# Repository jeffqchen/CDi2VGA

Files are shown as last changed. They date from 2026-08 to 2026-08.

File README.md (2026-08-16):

# HD15 Port Add-on for Phlips CD-i

## Introduction

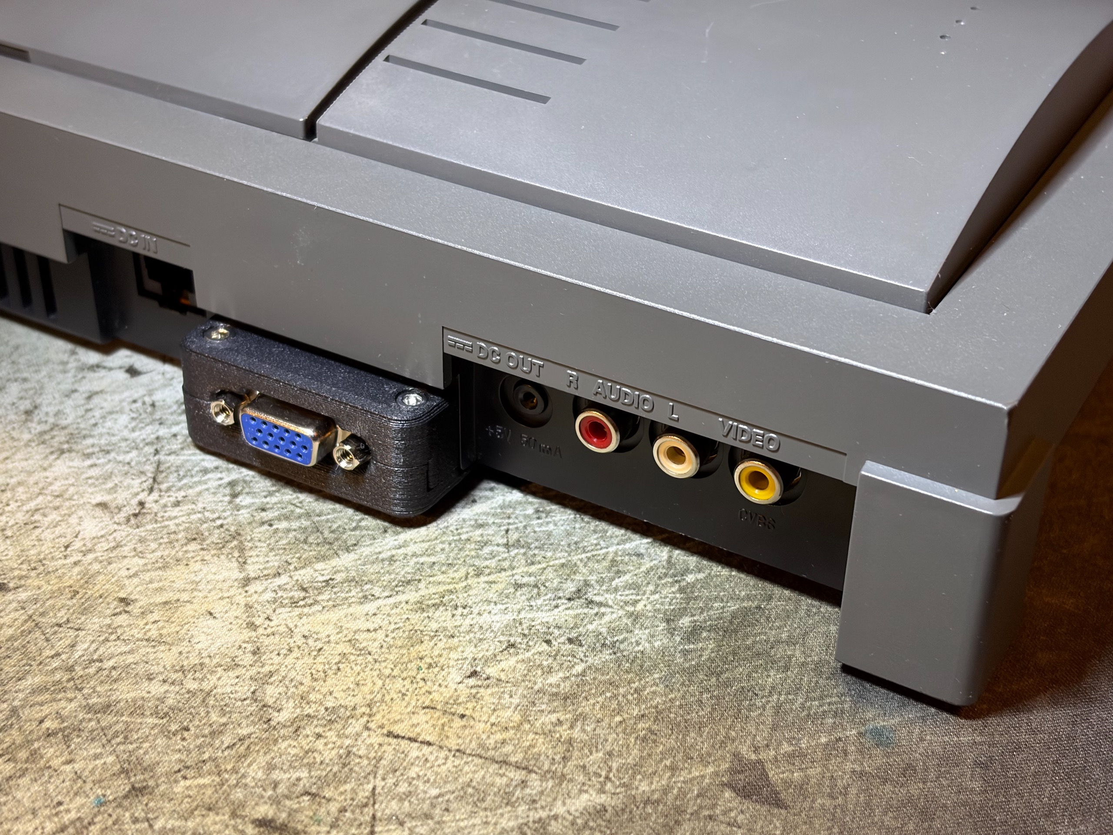
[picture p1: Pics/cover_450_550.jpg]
Philips CD-i 450 with HD15 Addon


The Philips CD-i can be modded with RGB output. However the actual output port sometimes involve cutting big holes or removing the Composite Video jack to fit. Therefore, I have come up this addon to fit an HD15 port onto the grills on the back of the console.

## Pin Definition

The pin definition follows the standard of my [VGA Dongle Series](https://github.com/jeffqchen/Console-VGA-Dongle-Series), which carries RGBS plus stereo audio.

- Pin 1-3: RGB signals
- Pin 13: HSync/CSync (connect to `CS-TTL` or `CS-75`)
- Pin 14: VSync (normally unpopulated)
- Pin 5, 6-8, 10: Ground
- Pin 12 & 15: Audio L & R
- Pin 9: Fused 5V

## Compatibility

This VGA signal is compatible with all major scalers.
- RetroTINK 5X - with my [dock](https://github.com/jeffqchen/RetroTINK-5X-SCART-Dock)
- RetroTINK 4K - directly connect to the `HD15` port or through my [SCART2VGA adapter](https://github.com/jeffqchen/RetroTINK-4K-SCART2VGA-Adapter)
- OSSC - directly connect to AV3 (VGA) port **IF** `CS_TTL` is connected to `Pin 13`
- GBSControl

## Currently supported Models
- CD-i 450 & 550 - [Guide](./450%20%26%20550/README.md)

-----------

Shield: [][cc-by-sa]

This work is licensed under a
[Creative Commons Attribution-ShareAlike 4.0 International License][cc-by-sa].

[][cc-by-sa]

[cc-by-sa]: http://creativecommons.org/licenses/by-sa/4.0/
[cc-by-sa-image]: https://licensebuttons.net/l/by-sa/4.0/88x31.png
[cc-by-sa-shield]: https://img.shields.io/badge/License-CC%20BY--SA%204.0-lightgrey.svg

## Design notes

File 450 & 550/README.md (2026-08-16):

# Building Guide for Philips CD-i 450 & 550

Cover

## Introduction

This variant fits the CD-i 450 & 550, since both share the same chassis and motherboard design. It utilizes a section of rear vents, and require two holes drilled on the bottom of the casing for installation. The final result is slick and does not require cutting additional holes or removing the Composite Video jack.

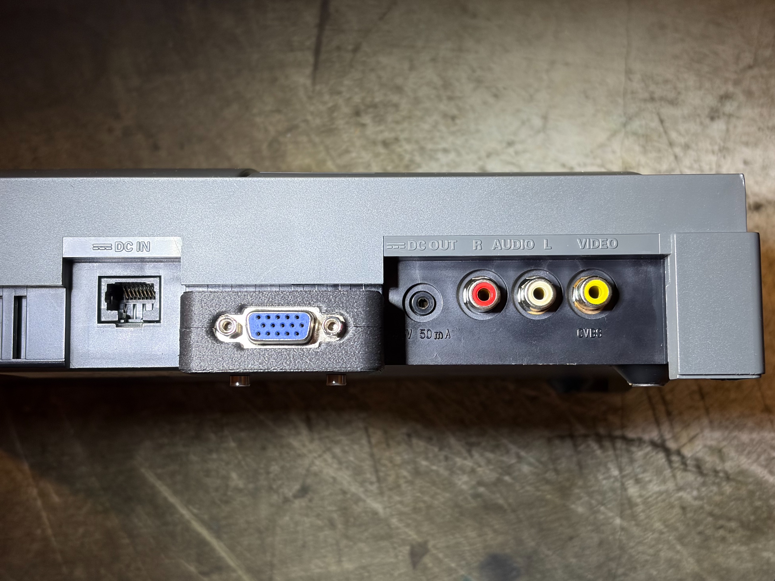
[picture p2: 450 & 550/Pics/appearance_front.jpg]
Front View

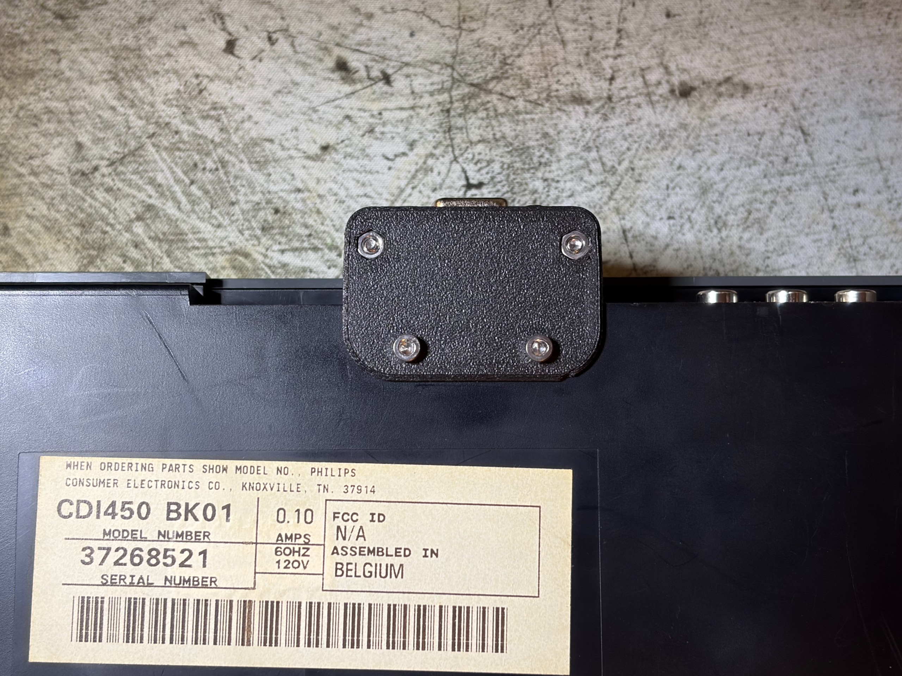
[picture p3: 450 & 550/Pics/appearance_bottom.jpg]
Bottom View

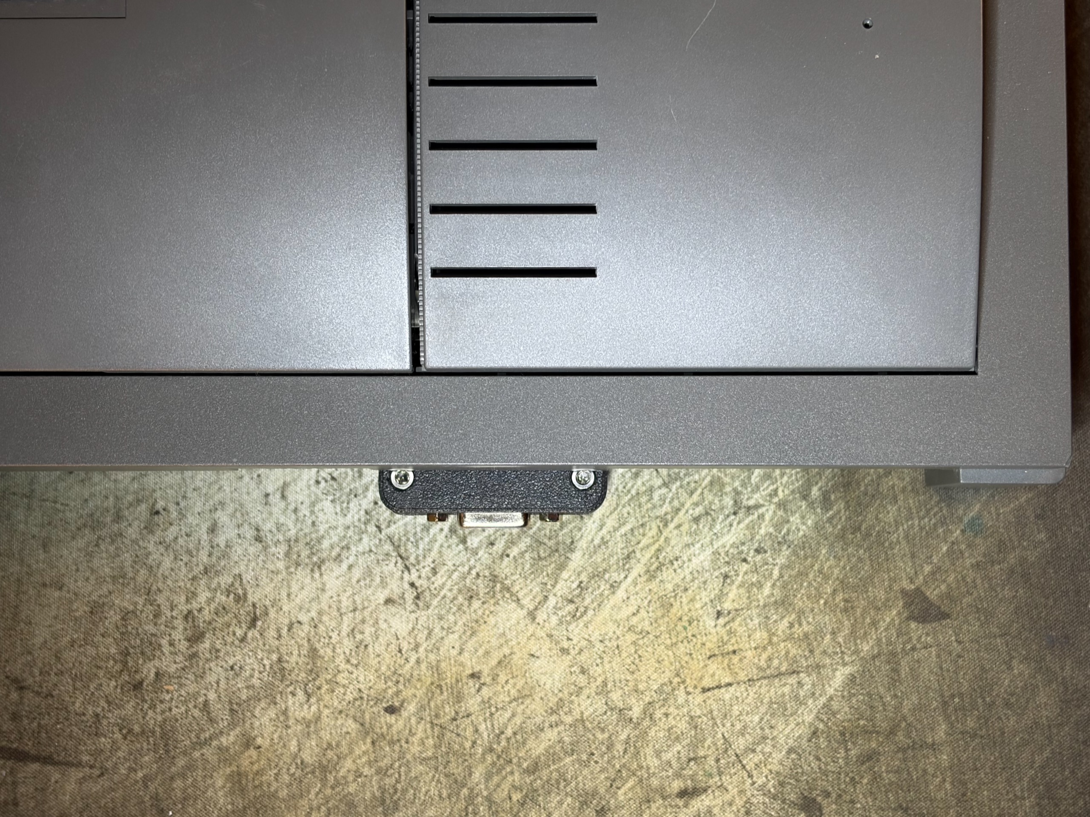
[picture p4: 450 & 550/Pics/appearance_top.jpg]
Top View


Since the original Composite Video jack is preserved, it is possible to output both CVBS and RGBS at the same time.

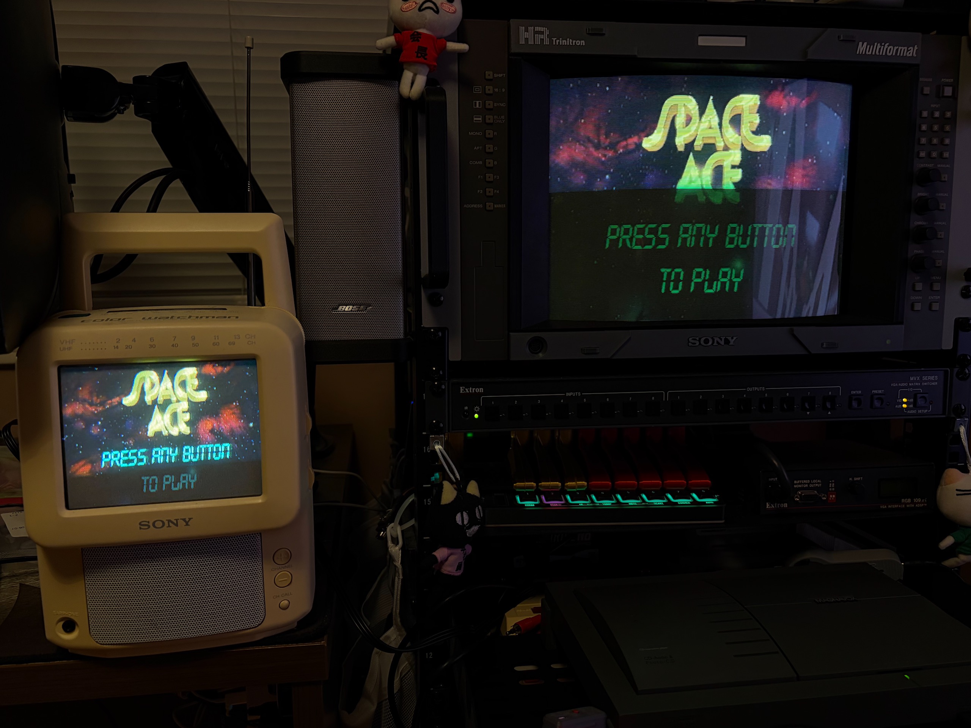
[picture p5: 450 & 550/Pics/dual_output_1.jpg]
Dual Output 1

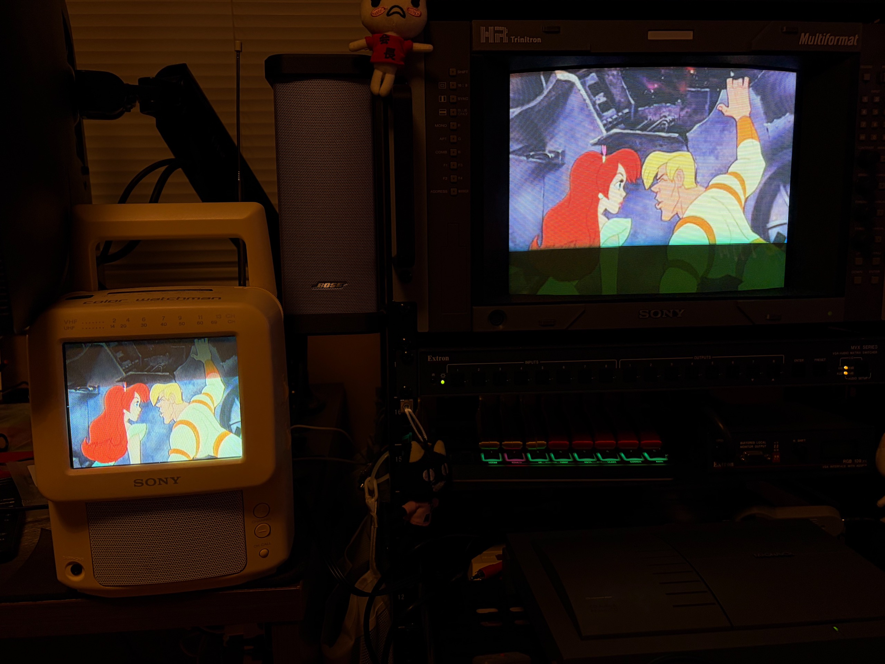
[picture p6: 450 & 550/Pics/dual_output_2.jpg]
Dual Output 2


## Parts

- 3D Printed parts - [STL Files](./3D%20Print)
- PCB - [Gerber File](./KiCAD/jlcpcb/gerber/CD-i%20450%20VGA%20Add-on.zip)
- VGA Port Slim, Female - [Link](https://github.com/jeffqchen/JeffParts/blob/main/Connectors/HD15/Slim/Female%20PCB/info.md)
- (Optional) Resistors, imperial 0603
  - R1: 0 Ohm, for fusing the 5V power line
  - R2: 1M Ohm, for connecting the VGA cable shielding to ground with ESD protection
- M2/M3 screw and hex nut - [Link](https://github.com/jeffqchen/JeffParts/blob/main/Parts/M2%20M3%20Hex%20Screw%20%26%20Nut/info.md)
  - 2x M3x8 screws
  - 2x M3x16 screws
  - 4x M3 nuts
- Colored wire at around 15cm

## Drilling The Chassis

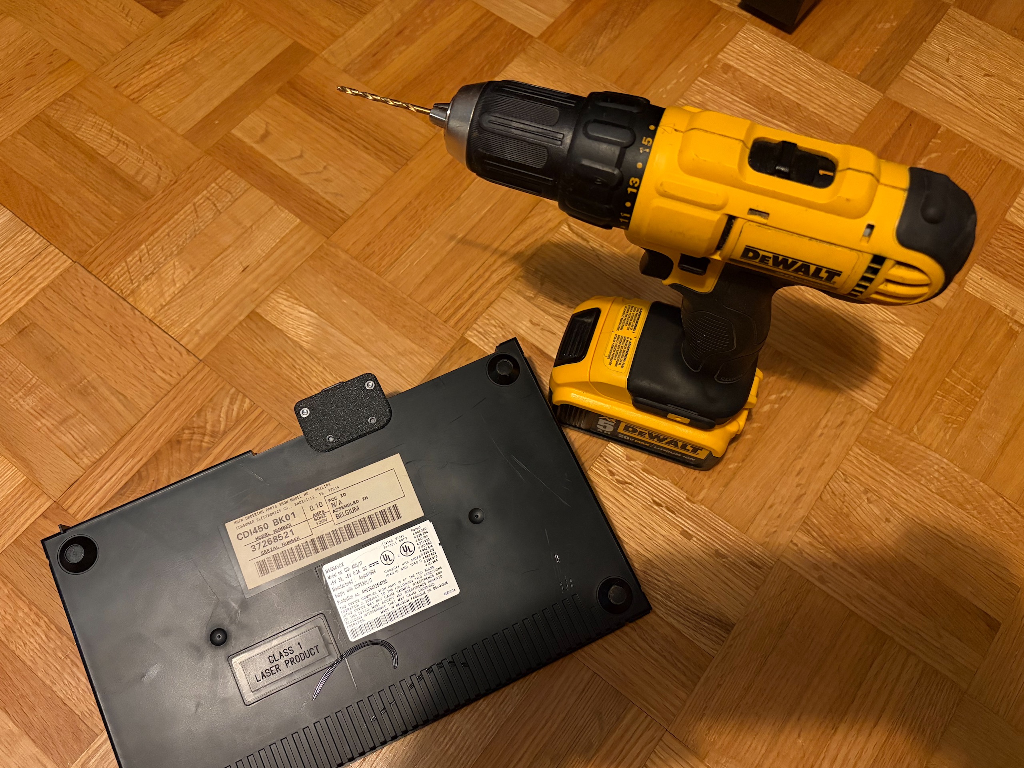
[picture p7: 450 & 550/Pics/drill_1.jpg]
Drilling 1


Assembly the 3D printed pieces together with screw and nuts, put it in place and use the two holes on the bottom as a guide to drill. The size of the bit should be 3mm / 1/8".

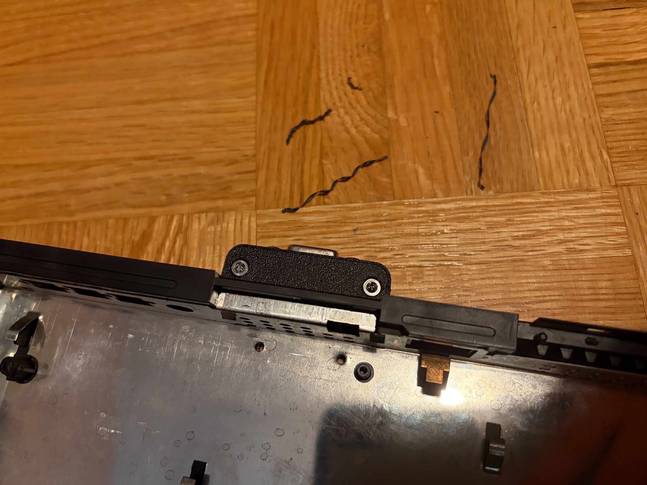
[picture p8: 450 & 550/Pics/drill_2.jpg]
Drilling 2


Fit a piece of wood on the inside of the metal shielding for taking the pressure of the drill. Make sure to drill through both the plastic and the metal shielding.

After the holes are drilled, remove the 3D printed shell and disassemble it for the next step.

## PCB & Shell Assembly

There is nothing special about the soldering.

Resistor R1 and R2 are optional if you have requirements for 5V power or ESD consideration.

Make sure the VGA port is soldered on properly with no gap between the base of the port and the PCB.

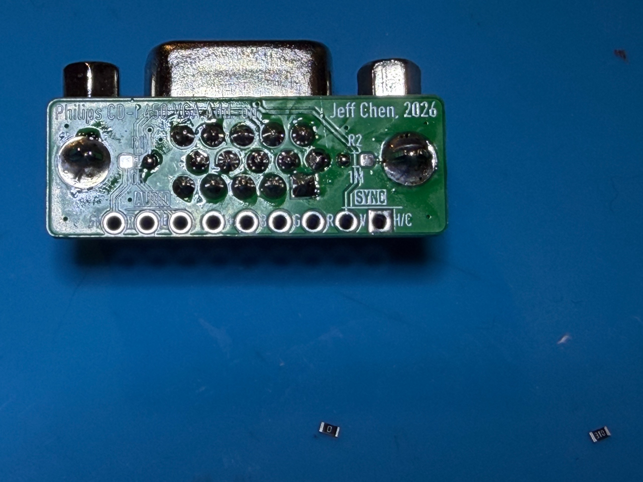
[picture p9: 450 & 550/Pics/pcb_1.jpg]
PCB Assembly 1


Signals are marked on the PCB. Use colored wires of your choice to help with later installation.

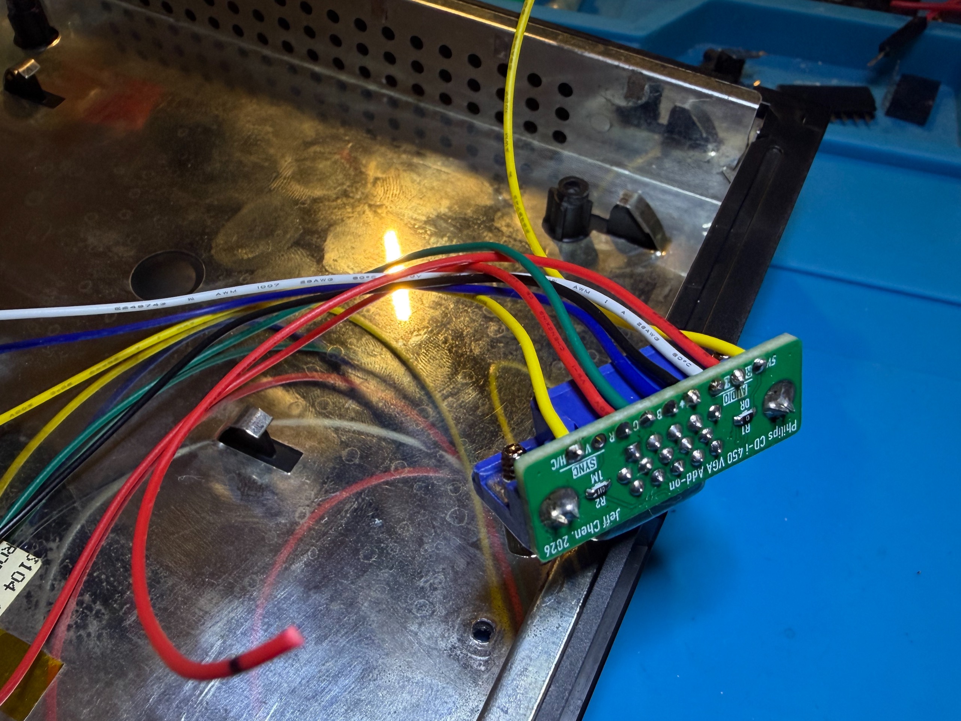
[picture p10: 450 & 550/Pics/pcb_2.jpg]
PCB Assembly 2


Finally, install the PCB assembly into the 3D printed shell with M3x16mm screws and nuts.

## Installation

Thread the wires from the various vents into the metal shielding.

Note the first and last vent are used by the shell and should not have wires going through them. 

On the inside, I mainly used the top row holes since the lower ones might interfere with the motherboard.

Make sure the wires are not played with or bent too much during this step, as they tend to break at the solder joint.

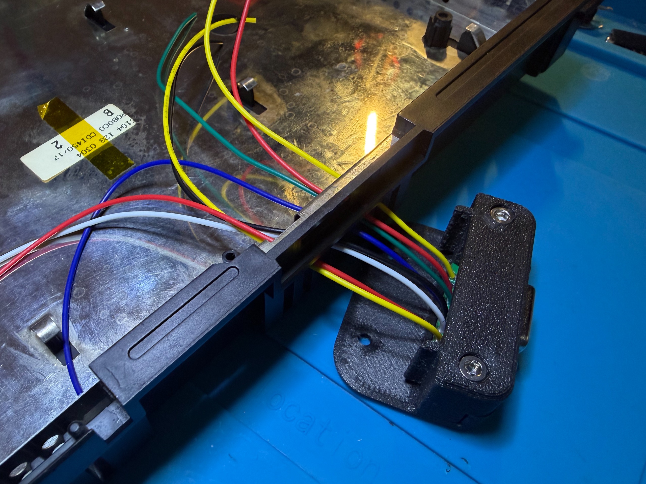
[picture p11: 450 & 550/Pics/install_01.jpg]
Installation 1

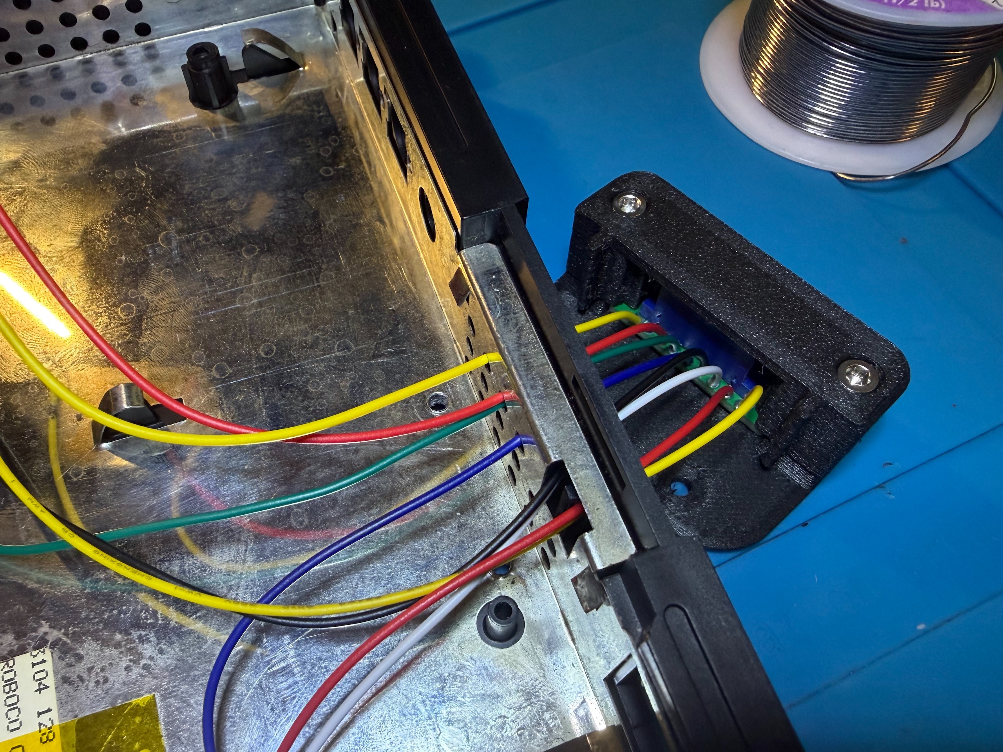
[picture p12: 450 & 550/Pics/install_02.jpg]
Installation 2


After threading all the wires, carefully close the port assembly onto the back of the plastic chassis.

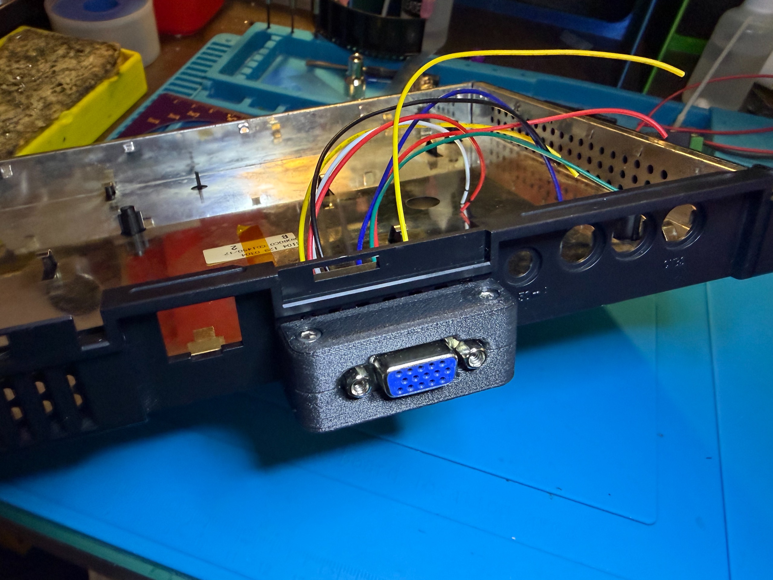
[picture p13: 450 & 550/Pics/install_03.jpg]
Installation 3

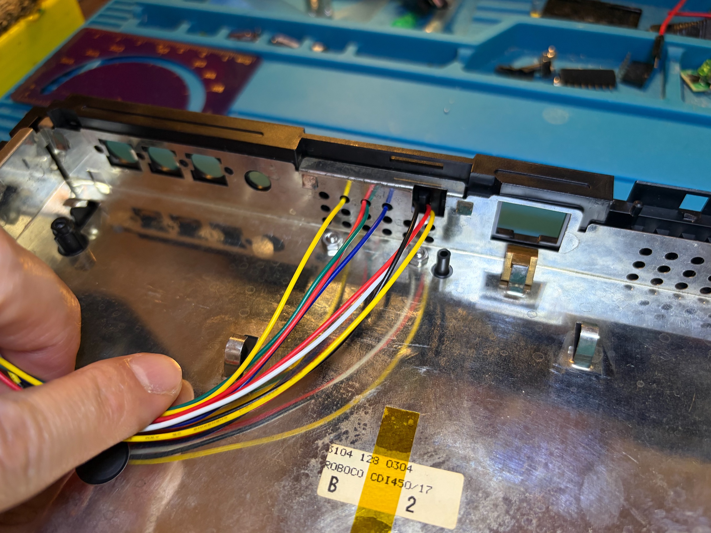
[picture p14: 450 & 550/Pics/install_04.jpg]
Installation 4


Insert two M3x8mm screws from the bottom of the console.

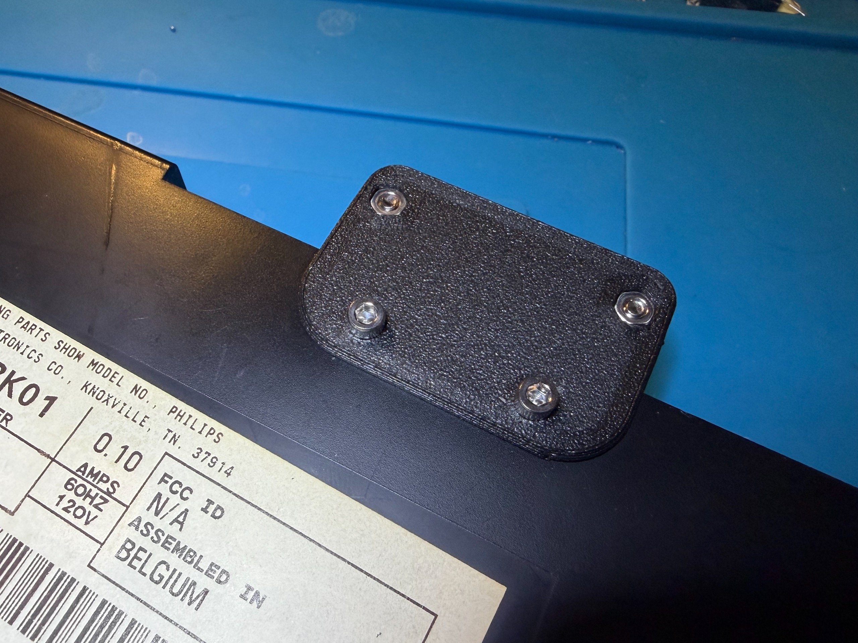
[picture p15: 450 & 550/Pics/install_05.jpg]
Installation 5


Use two M3 nuts to secure the screws and the assembly.

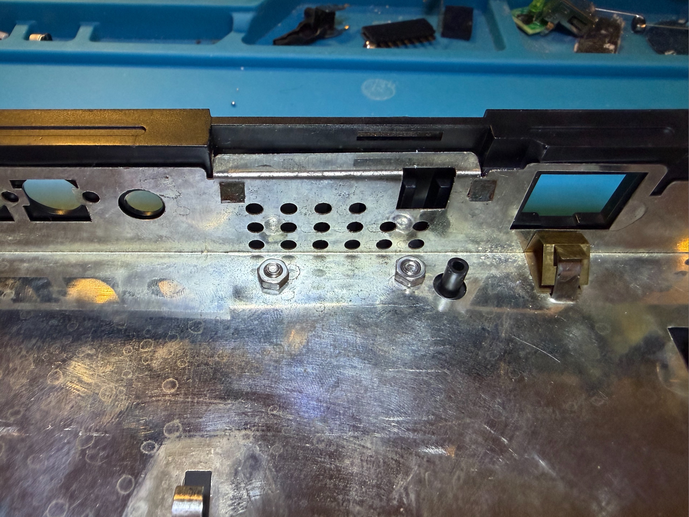
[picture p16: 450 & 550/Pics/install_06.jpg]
Installation 6


Before installing the motherboard back into the chassis, cut the 4 protruding capacitor leads from under the board to make sure they would not touch the newly installed nuts.

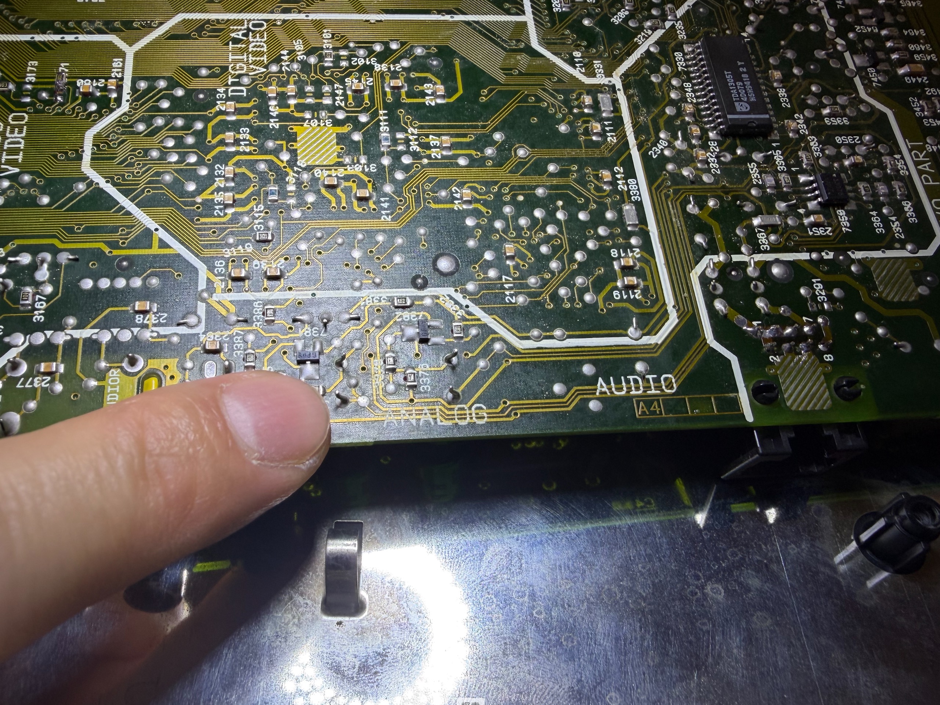
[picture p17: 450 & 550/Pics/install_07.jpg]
Installation 7


Install the motherboard and make sure all the wires are accounted for.

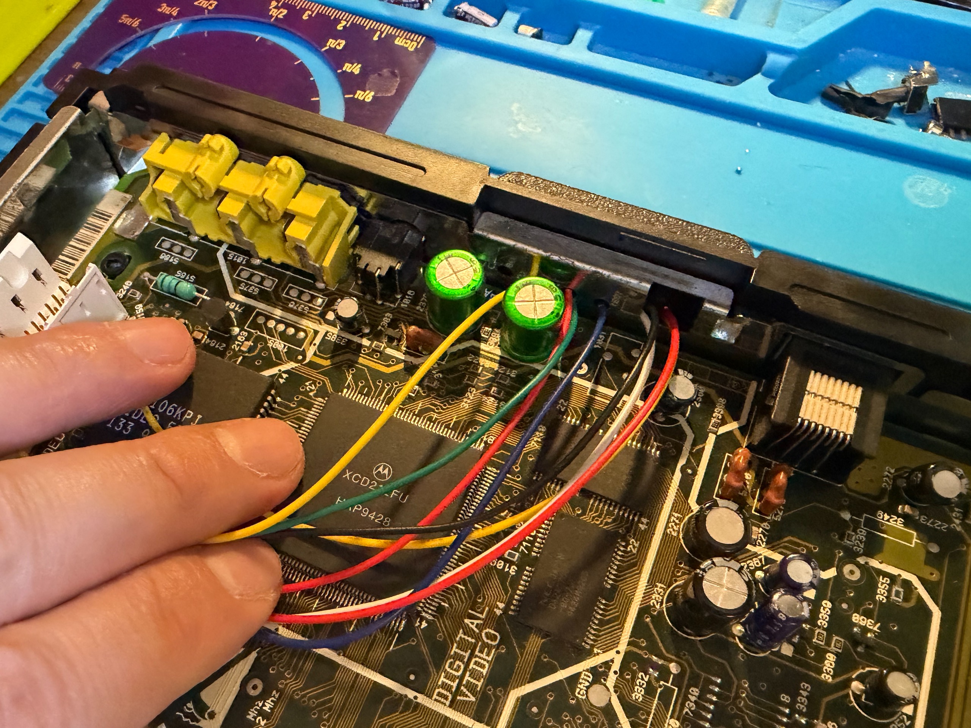
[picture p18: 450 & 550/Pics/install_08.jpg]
Installation 8


## Finalizing

Here is an example of my own RGB mod install. I trimmed the wires to better fit them on the inside of the console.

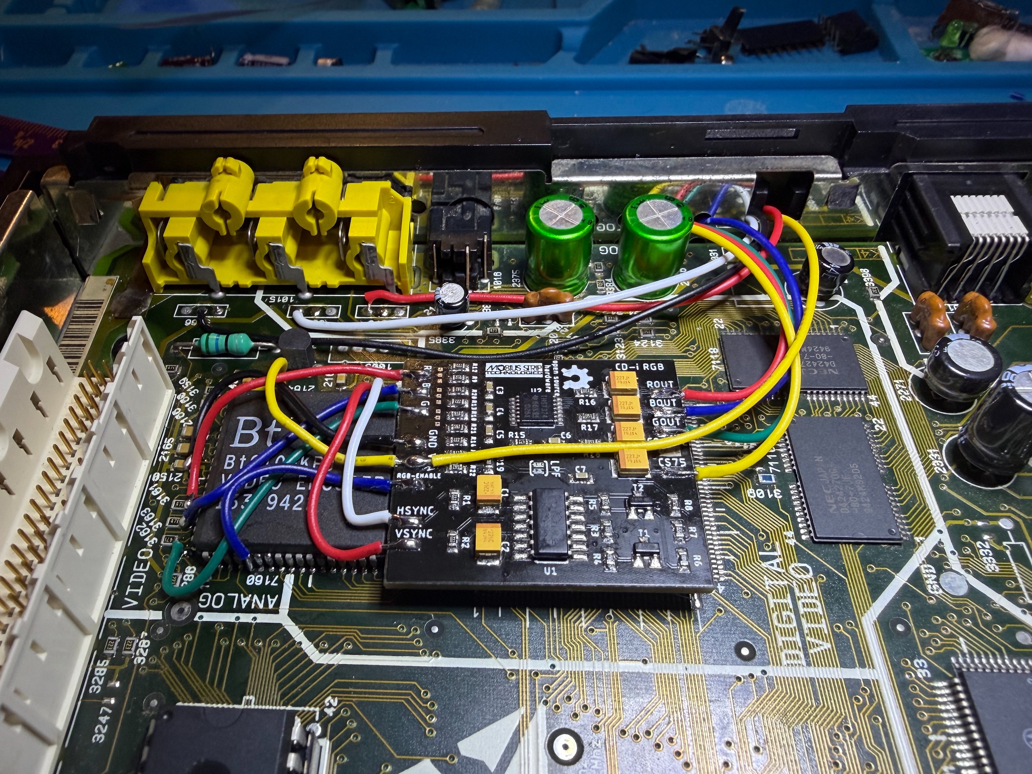
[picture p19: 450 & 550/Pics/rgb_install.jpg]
RGB Installation


When closing down the top metal shielding, make sure to check if any wire is being crushed by the edge of the top shielding (mine was fine.)

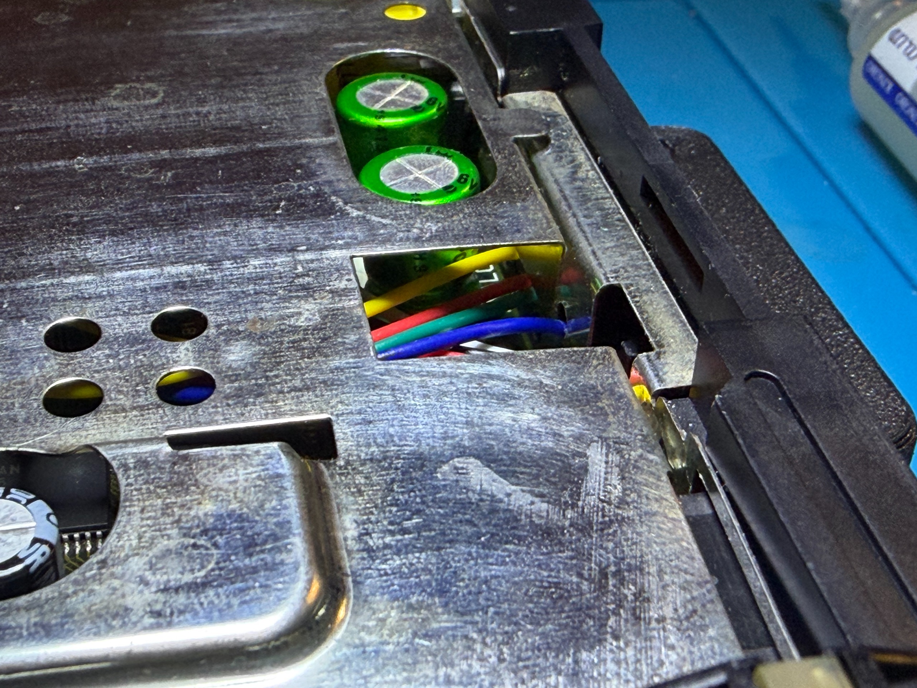
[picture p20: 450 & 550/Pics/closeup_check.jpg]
Closing check


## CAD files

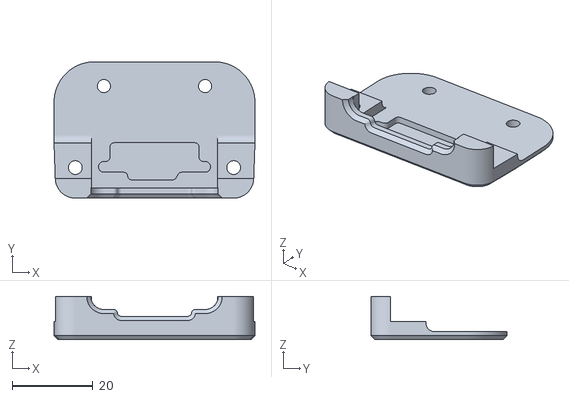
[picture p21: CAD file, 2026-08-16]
450 & 550/3D Print/Shell Bottom.stl
49.7 x 33.7 x 10.7

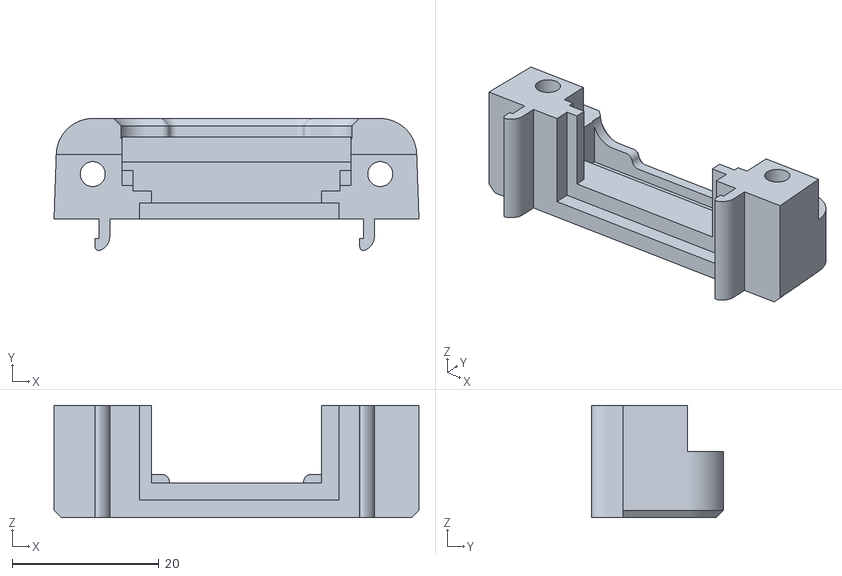
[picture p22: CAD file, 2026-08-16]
450 & 550/3D Print/Shell Top.stl
49.7 x 18.0 x 15.3

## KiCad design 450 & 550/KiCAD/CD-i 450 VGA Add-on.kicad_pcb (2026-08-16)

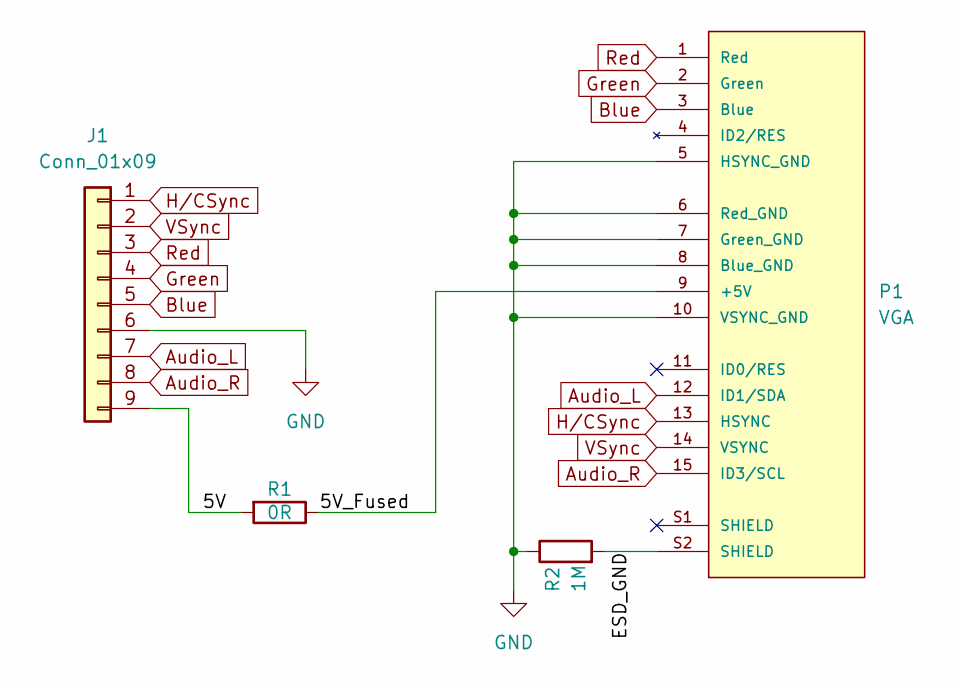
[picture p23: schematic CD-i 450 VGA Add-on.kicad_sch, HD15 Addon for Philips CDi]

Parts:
J1: Conn_01x09; PinHeader_1x09_P2.54mm_Vertical
P1: VGA; VGA_female_rightangle_slim; PARTREV N/A
R1: 0R; R_0603_1608Metric_Pad0.98x0.95mm_HandSolder
R2: 1M; R_0603_1608Metric_Pad0.98x0.95mm_HandSolder

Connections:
/5V: J1.9, R1.2
/5V_Fused: P1.9 (+5V), R1.1
/ESD_GND: P1.S2 (SHIELD), R2.2
Audio_L: J1.7, P1.12 (ID1/SDA)
Audio_R: J1.8, P1.15 (ID3/SCL)
Blue: J1.5, P1.3 (Blue)
GND: J1.6, P1.5 (HSYNC_GND), P1.6 (Red_GND), P1.7 (Green_GND), P1.8 (Blue_GND), P1.10 (VSYNC_GND), R2.1
Green: J1.4, P1.2 (Green)
H/CSync: J1.1, P1.13 (HSYNC)
Red: J1.3, P1.1 (Red)
VSync: J1.2, P1.14 (VSYNC)

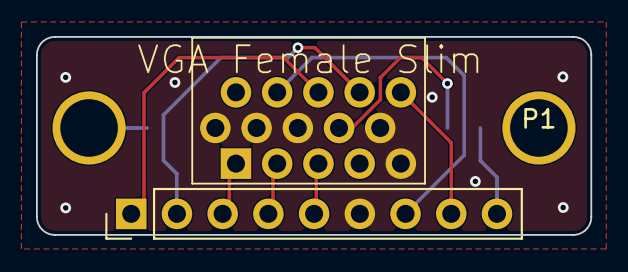
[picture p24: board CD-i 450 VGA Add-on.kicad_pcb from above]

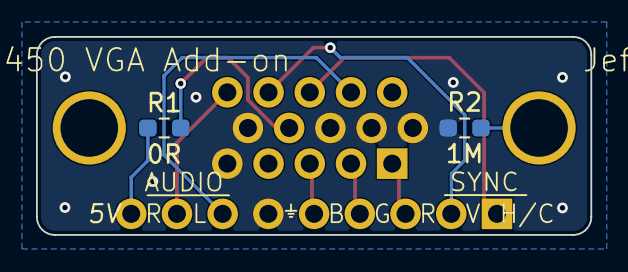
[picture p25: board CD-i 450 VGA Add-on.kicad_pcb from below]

Board: 2 copper layers, 30.8 x 11.0 mm, 4 parts (2 on the bottom side), 11 nets.

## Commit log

2026-08-16 Initial file upload for 450 & 550
    [CD-i 450 VGA Add-on-CuBottom.gbr, CD-i 450 VGA Add-on-CuTop.gbr, CD-i 450 VGA Add-on-EdgeCuts.gbr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]
2026-08-16 Update README with VGA pin definitions and compatibility
    Added pin definitions and compatibility information for VGA output.
2026-08-16 Add building guide for Philips CD-i 450 & 550
    Added detailed building guide for Philips CD-i 450 & 550, including parts list, PCB assembly instructions, and chassis drilling steps.
2026-08-16 Change PCB link to HTML anchor tag
    Updated the PCB link to use an HTML anchor tag for better accessibility.
2026-08-16 Enhance README with installation instructions and images
    Added images and detailed instructions for drilling, assembly, and installation of the VGA add-on for Philips CD-i 450 & 550.
2026-08-16 Update README with optional resistor information
    Added optional resistor details for 5V power and ESD protection in the assembly instructions.
2026-08-16 Update PCB assembly instructions in README.md
    Rearranged PCB assembly instructions and clarified optional components.
2026-08-16 Fix typo in README regarding resistor options
2026-08-16 Update installation instructions in README
    Clarified instructions for threading wires into metal shielding and noted vent usage.
2026-08-16 Refine wire installation instructions in README
    Reorganize instructions for clarity and emphasis on wire handling.
2026-08-16 Clarify instructions for using colored wires

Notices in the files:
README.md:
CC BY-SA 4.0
